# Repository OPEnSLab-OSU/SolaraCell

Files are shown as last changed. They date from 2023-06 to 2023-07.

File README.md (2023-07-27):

Project Creator: Aiden Olsen

The purpose of the SolaraCell is simple, provide solar lipo charging without needing to arrange
the components on the end PCB yourself. The SolaraCell uses the BQ24074 smart charging IC allowing
you to power your projects.

<!-- More information about assembly, testing, and operation can be found at the wiki. -->

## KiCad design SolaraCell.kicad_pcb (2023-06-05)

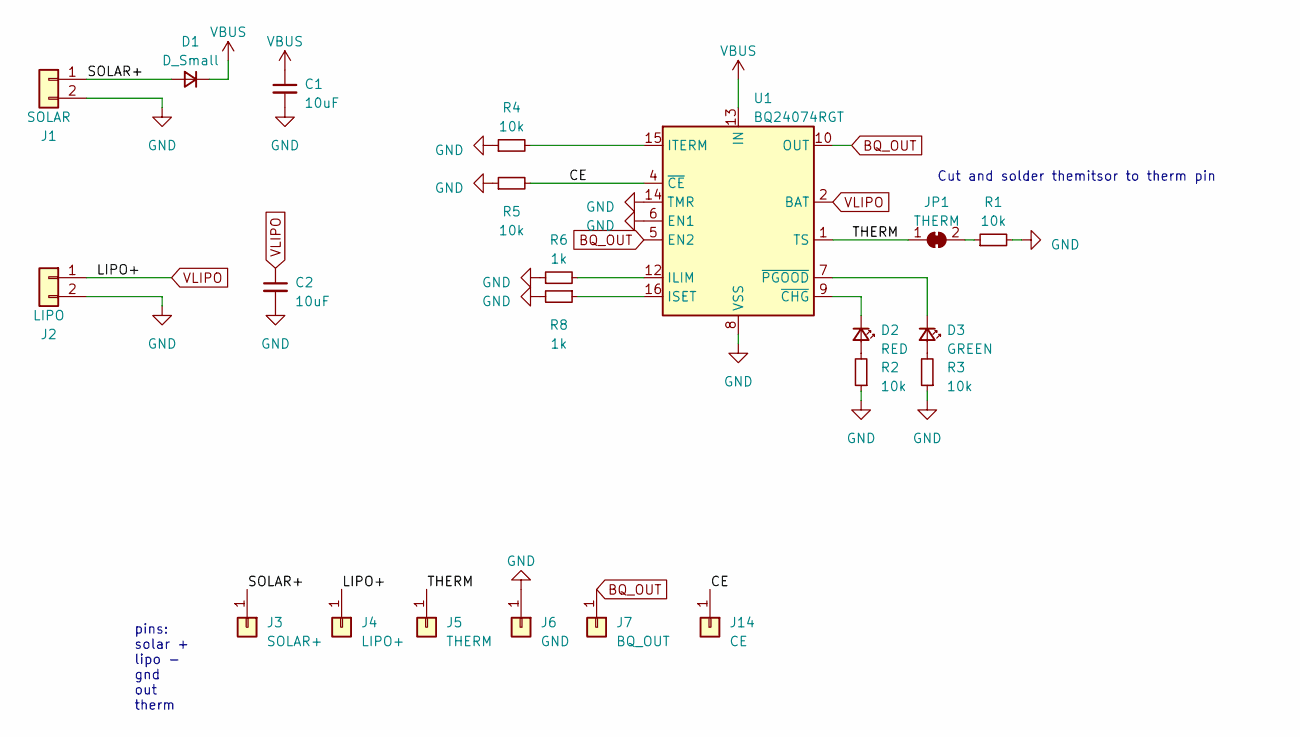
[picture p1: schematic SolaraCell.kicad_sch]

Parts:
C1, C2: 10uF; C_0805_2012Metric
D1: D_Small; D_SOD-123
D2: RED; LED_0805_2012Metric
D3: GREEN; LED_0805_2012Metric
J1: SOLAR; TerminalBlock_TE_282834-2_1x02_P2.54mm_Horizontal
J2: LIPO; JST_PH_S2B-PH-SM4-TB_1x02-1MP_P2.00mm_Horizontal
J3: SOLAR+; PCBWay_CastellatedHole
J4: LIPO+; PCBWay_CastellatedHole
J5: THERM; PCBWay_CastellatedHole
J6: GND; PCBWay_CastellatedHole
J7: BQ_OUT; PCBWay_CastellatedHole
J14: CE; PCBWay_CastellatedHole
JP1: THERM; SolderJumper-2_P1.3mm_Bridged_RoundedPad1.0x1.5mm
R1, R2, R3, R4, R5: 10k; R_0805_2012Metric
R6, R8: 1k; R_0805_2012Metric
U1: BQ24074RGT; VQFN-16-1EP_3x3mm_P0.5mm_EP1.6x1.6mm

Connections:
/CE: J14.1, R5.2, U1.4 (~CE)
/SOLAR+: D1.2 (A), J1.1, J3.1
/THERM: J5.1, JP1.1 (A), U1.1 (TS)
BQ_OUT: J7.1, U1.5 (EN2), U1.10 (OUT), U1.11 (OUT)
GND: C1.2, C2.2, J1.2, J2.2, J6.1, R1.2, R2.1, R3.1, R4.1, R5.1, R6.1, R8.2, U1.6 (EN1), U1.8 (VSS), U1.14 (TMR), U1.17 (VSS)
unnamed: D2.2 (A), R2.2
unnamed: D2.1 (K), U1.9 (~CHG)
unnamed: D3.2 (A), R3.2
unnamed: D3.1 (K), U1.7 (~PGOOD)
unnamed: JP1.2 (B), R1.1
unnamed: R6.2, U1.12 (ILIM)
unnamed: R8.1, U1.16 (ISET)
unnamed: R4.2, U1.15 (ITERM)
VBUS: C1.1, D1.1 (K), U1.13 (IN)
VLIPO: C2.1, J2.1, J4.1, U1.2 (BAT), U1.3 (BAT)

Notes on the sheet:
pins: solar + lipo - gnd out therm
Cut and solder themitsor to therm pin

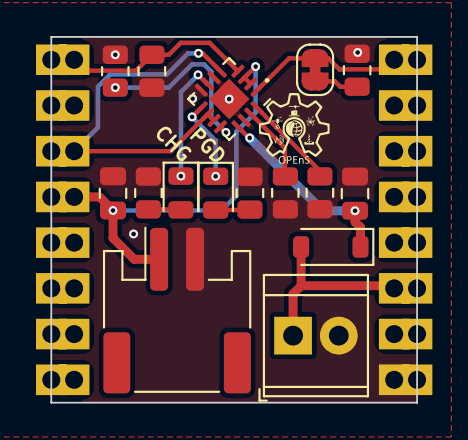
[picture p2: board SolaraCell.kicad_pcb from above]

Board: 2 copper layers, 20.3 x 20.3 mm, 22 parts (0 on the bottom side), 15 nets.
